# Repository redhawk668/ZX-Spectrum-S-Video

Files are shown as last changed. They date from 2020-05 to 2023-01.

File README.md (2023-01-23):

# Introduction

This PCB replaces the RF modulatorbox on a Sinclair ZX Spectrum computer. It's main purpose is to improve the video output of the ZX Spectrum by seperating the luma/sync (Y) and chroma (C) signals to get rid of the dotcrawl.

# Composite output works, why designing this board?
Why not? I use a RetroTink 2X (https://www.retrotink.com/product-page/retrotink-2x), this little device converts an analog signal to HDMI output. The Spectrum's composite output is absolutely horrible on this. The RetroTink provides an s-video input, that gave me the idea to seperate the Y/C signals to convert the composite output to s-video, improving the video signal. Some googling later I found this thread on the World of Spectrum forums: 

https://www.worldofspectrum.org/forums/discussion/47120/new-video-about-s-video-modification-on-issue-two-48k-spectrum/p1. 

(Credits to MAK1024 and RGA24 for providing the basics for this design).

# The PCB itself

# Rev. A - Simple through hole design (first design)
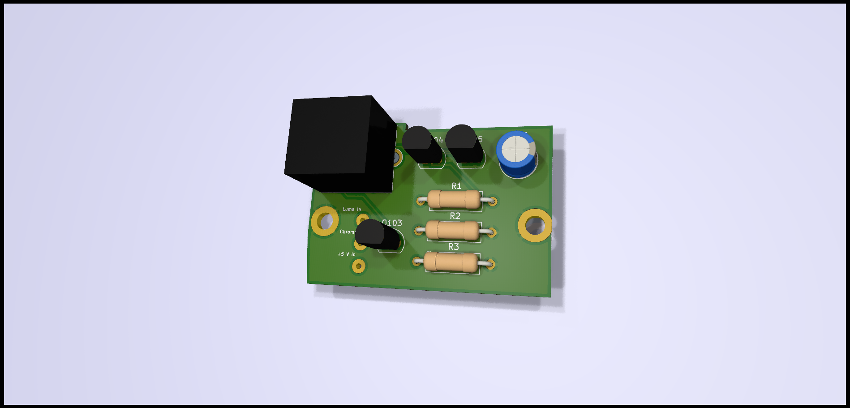
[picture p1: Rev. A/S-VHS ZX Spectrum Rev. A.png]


# Rev. D01 - Final design
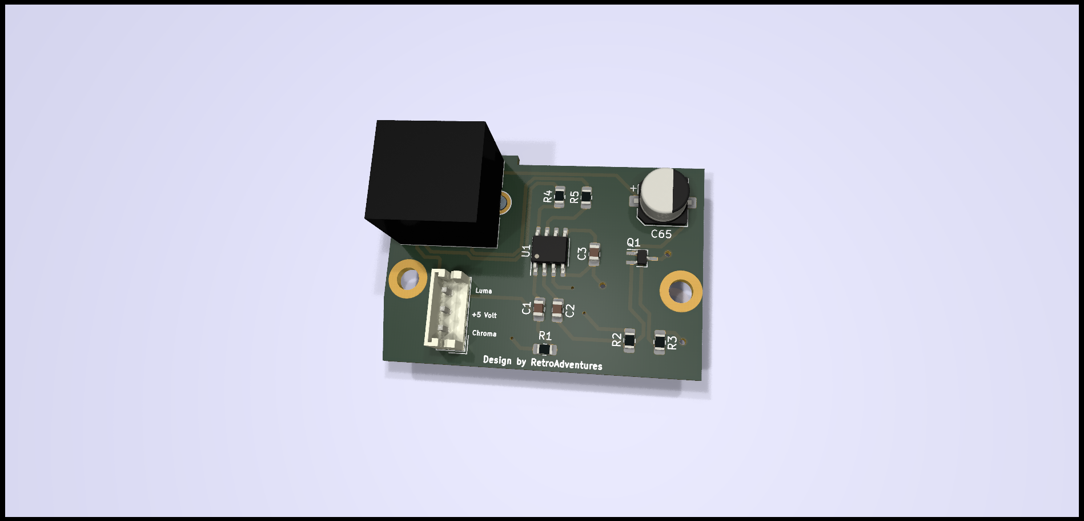
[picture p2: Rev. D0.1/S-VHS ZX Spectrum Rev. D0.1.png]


Rev. A is a through hole design and uses transistors to amplify the signal. 

Rev. D01 is the final design and like the previous Rev. D, based on the THS7314D chip. Two resistors have been removed, this was causing a dim picture on some displays. This design is also a 4-layer with seperated ground/power planes. For the connection to the ZX Spectrum a JST connector is used.

I have included the Gerber files from each design, so you can have the PCB of your choice manufactured by your preferred manufacturer.

# Billing of Materials: Rev. A
- 1x 4 pin mini din chassis (Lumberg TM 0508 A/4)
- 3x NPN Transistors. I've used BC547, but most small signal transistors should be fine.
- 1x 2K2 Resistor
- 1x 3K9 or 1x 4K3 Resistor
- 1x 390R Resistor
- 1x 22uF Electrolytic Capacitor

# Billing of Materials: Rev. D.01 (Final Design)
- J1: 1x 4 pin mini din chassis (Lumberg TM 0508 A/4)
- Q1: BC847, SOT323/SC70
- U1: THS7314D, SOIC-8
- C1: 0,1 uF ceramic capacitor XR7, 0805
- C2: 0,1 uF ceramic capacitor XR7, 0805
- C3: 0,1 uF ceramic capacitor XR7, 0805
- C65: 22 uF aluminium electrolytic capacitor (6,3x5,3)
- R1: 1K thick film resistor, 0805
- R2: 390R thick film resistor, 0805
- R3: 2K2 thick film resistor, 0805
- R4: 75R thick film resistor, 0805
- R5: 75R thick film resistor, 0805
- J2: 3x01 JST connector 2.54mm spacing

# For Rev. A designs (Rev D.01 has JST connector):

- Some wire
- 2x M2.5 screws
- 4x M2.5 nuts

# Summary
Once you have built the little circuit, solder in wires for luma in, chroma in and +5 volt in. Make the wires for luma in and +5 volt about 50mm. PCB layout on an Issue 2 is a bit different than Issue 3 and above. 50mm for the chroma wire should be long enough for an Issue 2. Issue 3 and above needs a bit longer wire. 

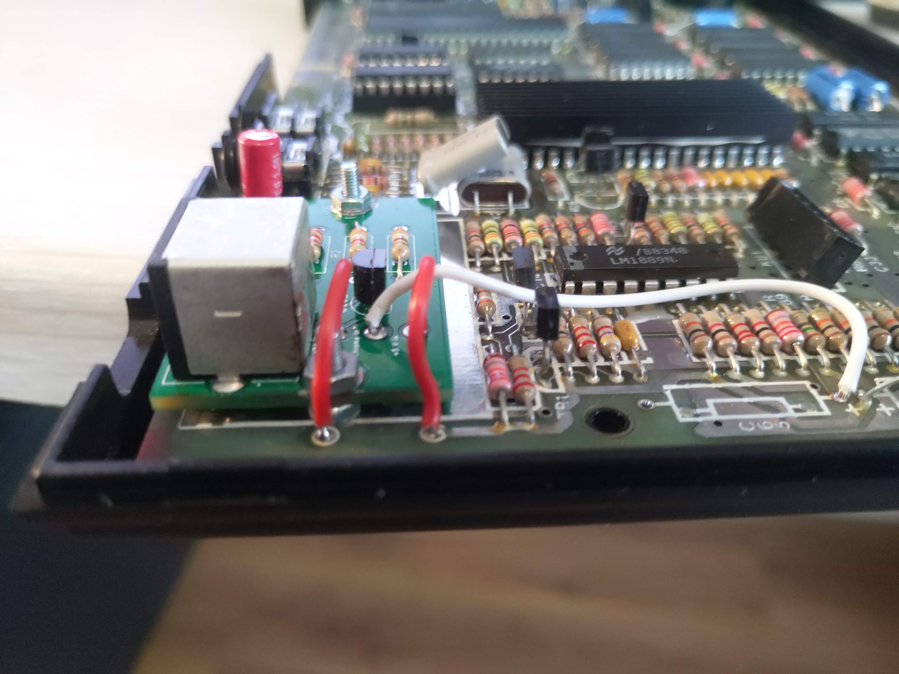
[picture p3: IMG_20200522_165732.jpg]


Now, carefully remove the modulatorbox and capacitor C65 from the Spectrum PCB. Now carefully mount the PCB onto the Spectrum PCB using the screws and nuts (might need drilling, but M2.5 should fit). Seperate the PCB's using one of the nuts on either side. Tighten the PCB to the Spectrum PCB using a nut on either side, as shown in the picture:

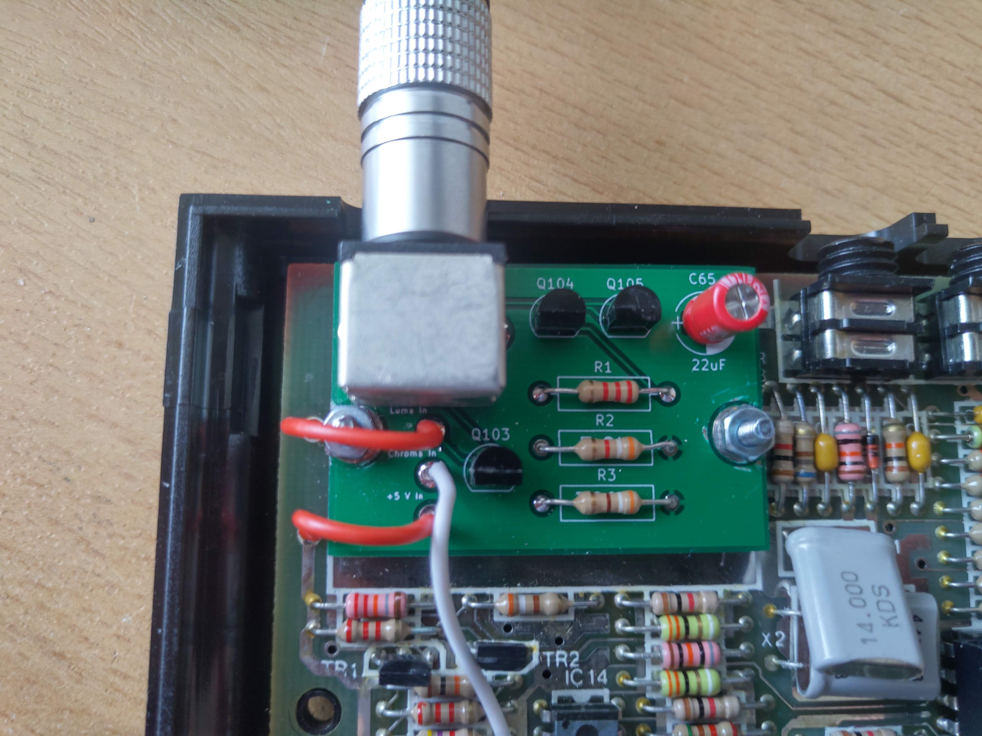
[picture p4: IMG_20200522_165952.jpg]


Now solder the luma and +5 volt into their respective holes. (The composite output on the Spectrum is now the luma output). Solder the chroma wire into the the + side of capacitor C65. On Issue 2 PCB's C65 is underneath the modulator box, on Issue 3 boards and above, C65 is above C25 on the left side of the PCB.

# Issue 2:

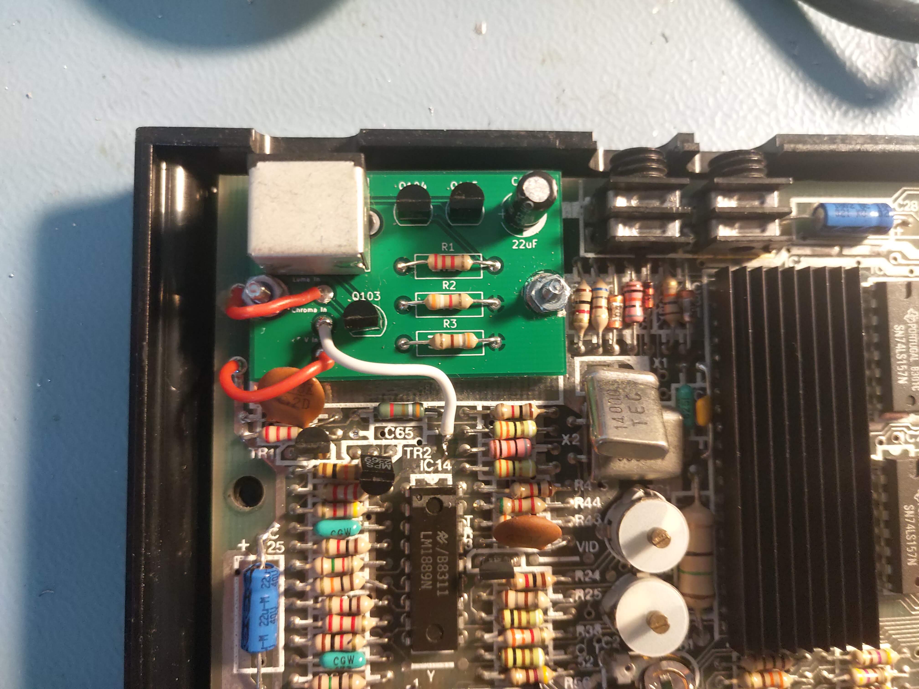
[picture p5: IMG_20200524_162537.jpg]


# Issue 3 and above:



# Rev. D01 connection to ZX Spectrum:

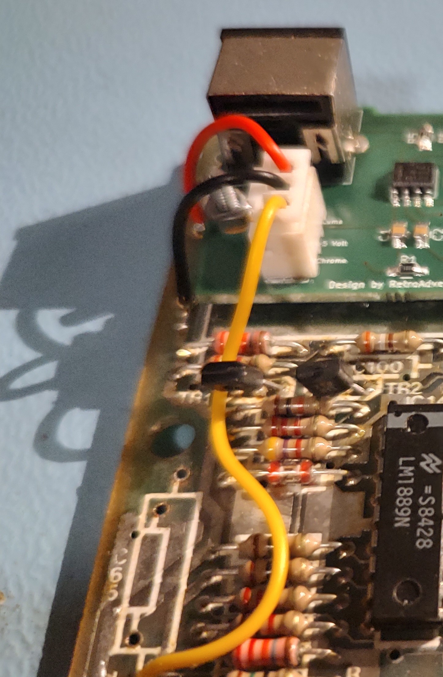
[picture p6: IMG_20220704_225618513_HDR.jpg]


I recommend cutting the pins of the mini din chassis as close to the underside of the PCB as possible, to prevent short circuits. 

# Disclaimer
I am not responsible for any damage to your Spectrum, you do this at your own risk. Take care when you build this and when fitting it to your Spectrum.

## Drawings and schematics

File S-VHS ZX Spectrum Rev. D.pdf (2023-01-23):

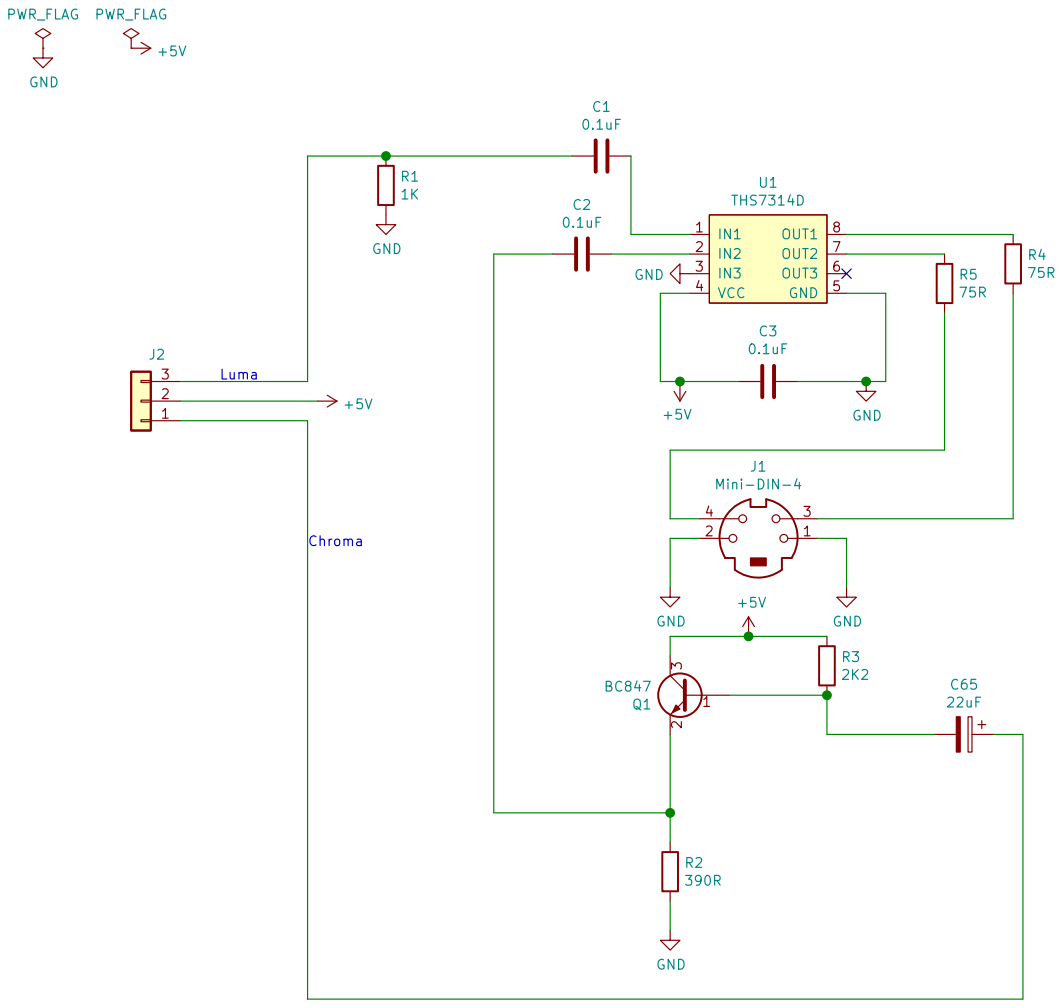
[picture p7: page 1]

File: S-VHS ZX Spectrum Rev. D.sch Sheet: /
Id: 1/1 Title:

ZX Spectrum S-Video Output 19-10-2020

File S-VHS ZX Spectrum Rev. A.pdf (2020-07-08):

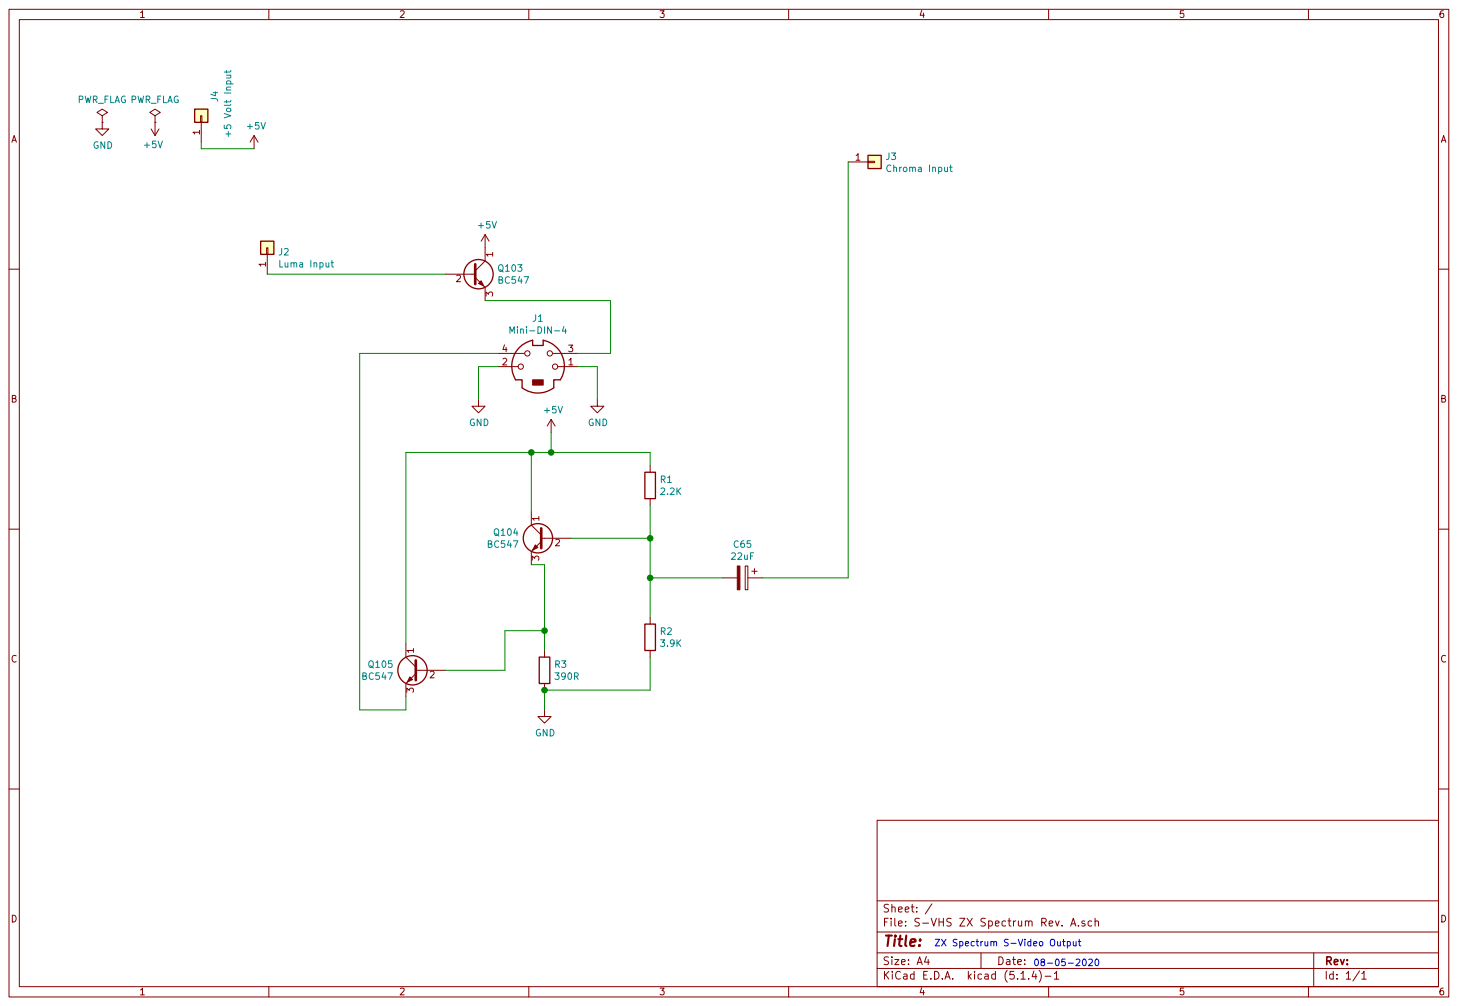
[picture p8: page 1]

File: S-VHS ZX Spectrum Rev. A.sch Sheet: /
Id: 1/1 Title:

ZX Spectrum S-Video Output 08-05-2020

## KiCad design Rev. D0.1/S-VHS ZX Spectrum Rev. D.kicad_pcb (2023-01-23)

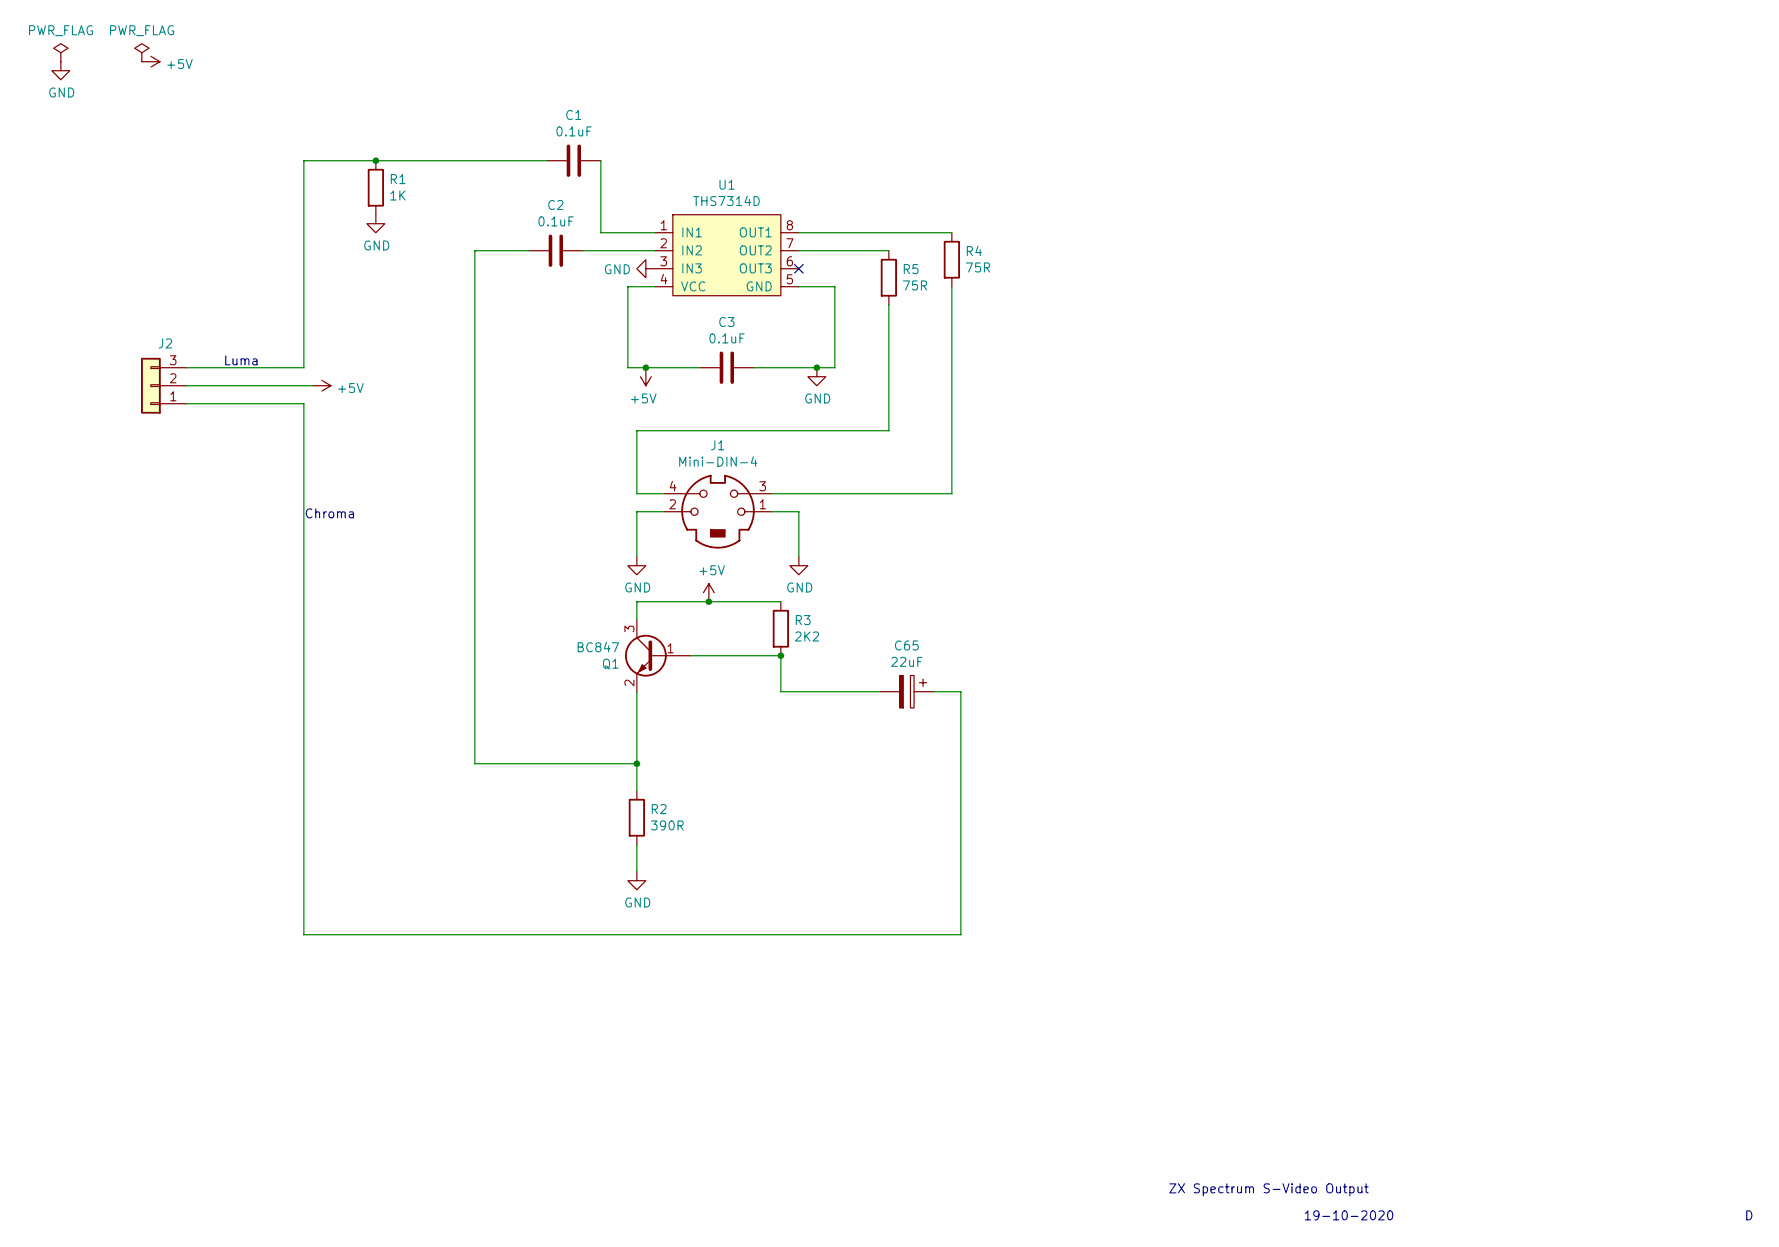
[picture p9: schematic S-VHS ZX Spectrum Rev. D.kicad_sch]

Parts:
C1, C2, C3: 0.1uF; C_0805_2012Metric_Pad1.18x1.45mm_HandSolder
C65: 22uF; CP_Elec_6.3x5.3
J1: Mini-DIN-4; MD40SMK
J2: Conn_01x03; JST_EH_B3B-EH-A_1x03_P2.50mm_Vertical
Q1: BC847; SOT-323_SC-70_Handsoldering
R1: 1K; R_0805_2012Metric_Pad1.20x1.40mm_HandSolder
R2: 390R; R_0805_2012Metric_Pad1.20x1.40mm_HandSolder
R3: 2K2; R_0805_2012Metric_Pad1.20x1.40mm_HandSolder
R4, R5: 75R; R_0805_2012Metric_Pad1.20x1.40mm_HandSolder
U1: THS7314D; SOIC-8_3.9x4.9mm_P1.27mm

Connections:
+5V: C3.1, J2.2, Q1.3 (C), R3.1, U1.4 (VCC)
GND: C3.2, J1.1, J1.2, R1.2, R2.2, U1.3 (IN3), U1.5 (GND); also elsewhere on the board
unnamed: C1.1, U1.1 (IN1)
unnamed: C1.2, J2.3, R1.1
unnamed: C2.1, U1.2 (IN2)
unnamed: C2.2, Q1.2 (E), R2.1
unnamed: C65.1, J2.1
unnamed: C65.2, Q1.1 (B), R3.2
unnamed: J1.3, R4.2
unnamed: J1.4, R5.2
unnamed: R4.1, U1.8 (OUT1)
unnamed: R5.1, U1.7 (OUT2)

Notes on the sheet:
Chroma
Luma
19-10-2020
ZX Spectrum S-Video Output

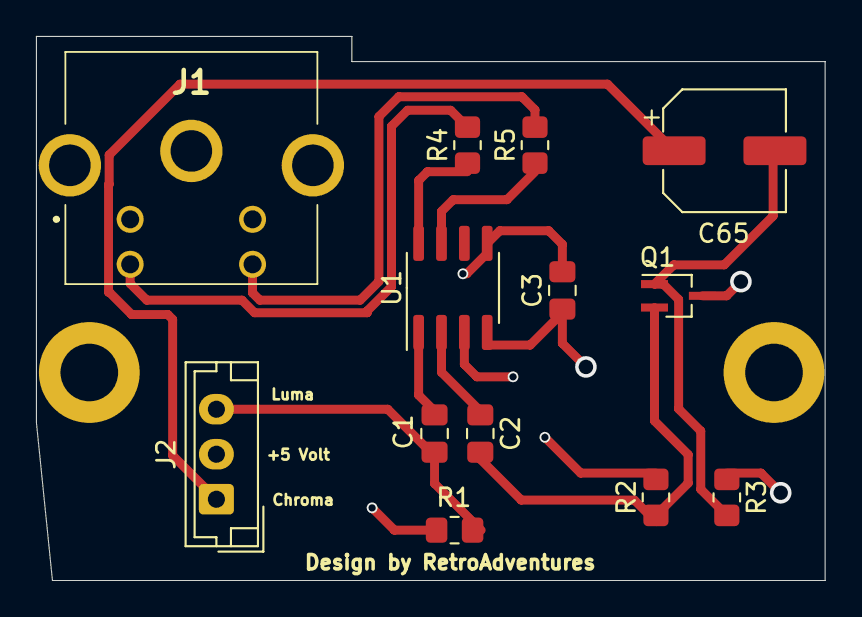
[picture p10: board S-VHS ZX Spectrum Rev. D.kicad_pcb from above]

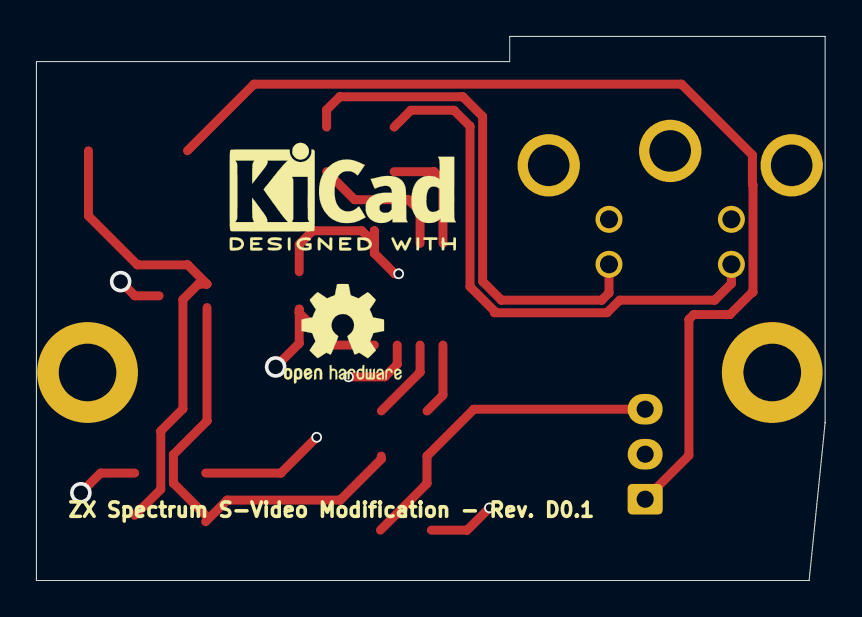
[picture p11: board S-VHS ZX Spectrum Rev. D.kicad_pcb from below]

Board: 4 copper layers, 43.8 x 30.2 mm, 17 parts (2 on the bottom side), 12 nets.

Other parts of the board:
KiCad Logo: KiCad-Logo2_6mm_SilkScreen
Left MountHole: MountingHole_3.2mm_M3_DIN965_Pad
Open Hardware Logo: OSHW-Logo2_7.3x6mm_SilkScreen
Right MountHole: MountingHole_3.2mm_M3_DIN965_Pad

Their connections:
GND: Left MountHole.1, Right MountHole.1; also elsewhere on the board

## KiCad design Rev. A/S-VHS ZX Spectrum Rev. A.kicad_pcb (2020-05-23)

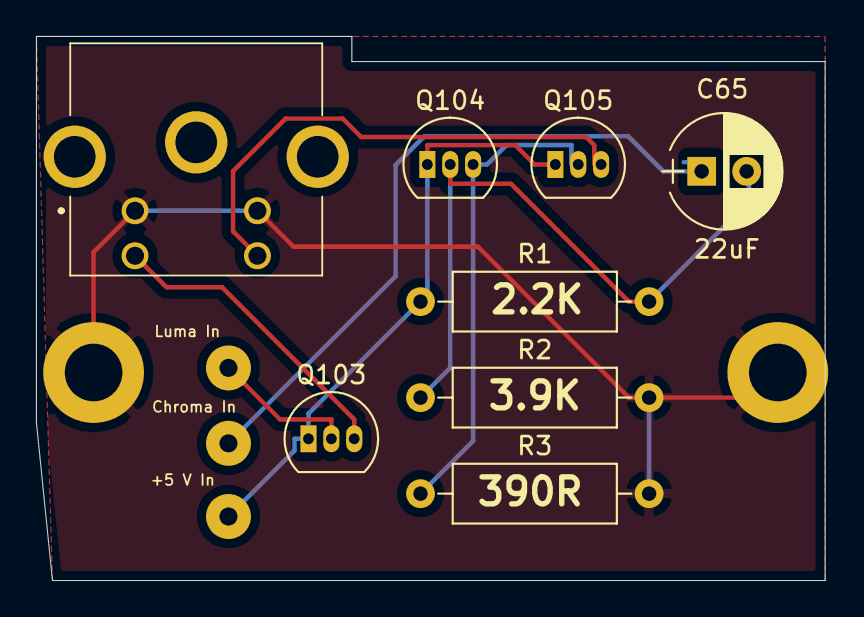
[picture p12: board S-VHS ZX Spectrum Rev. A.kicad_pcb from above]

Board: 2 copper layers, 43.8 x 30.2 mm, 13 parts (0 on the bottom side), 8 nets.

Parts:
C65: 22uF; CP_Radial_D6.3mm_P2.50mm
J1: Mini-DIN-4; MD40SMK
J2, J3, J4: SolderWirePad_single_1mmDrill
Q103, Q104, Q105: BC547; TO-92_Inline_Narrow_Oval
R1: 2.2K; R_Axial_DIN0309_L9.0mm_D3.2mm_P12.70mm_Horizontal
R2: 3.9K; R_Axial_DIN0309_L9.0mm_D3.2mm_P12.70mm_Horizontal
R3: 390R; R_Axial_DIN0309_L9.0mm_D3.2mm_P12.70mm_Horizontal
REF1, REF2: MountingHole_3.2mm_M3_DIN965_Pad

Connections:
+5V: J4.1, Q103.1, Q104.1, Q105.1, R1.1
GND: J1.1, J1.2, R2.2, R3.2, REF1.1, REF2.1
unnamed: C65.1, J3.1
unnamed: C65.2, Q104.2, R1.2, R2.1
unnamed: J1.3, Q103.3
unnamed: J1.4, Q105.3
unnamed: J2.1, Q103.2
unnamed: Q104.3, Q105.2, R3.1

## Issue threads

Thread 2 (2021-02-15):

ZX Spectrum 128K toastrack compatibility

cfrussen, 2021-02-15:
Hello, is this mod compatible with the ZX Spectrum 128K toastrack ?

redhawk668, 2021-02-15:
Unfortunately not, the ZX 128K has a different video circuit based on a TAE2000 video encoder chip.

mvbhz, 2025-07-18:
Will this modification fit the ZX Spectrum+? (ZX Spectrum+ compatibility)?

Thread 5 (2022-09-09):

Get no picture after applying the mod Rev.D

Snocksman, 2022-09-09:
Hi !

I build the mod Rev.D and applied it to my ZX Spectrum - Issue Two Board, but i don´t get any picture anymore...

What could be wrong ? Is there something i can check with the multimeter ? Do I still have to set up the picture with the onboard Potentiometer ?

I measured the voltage on the three connections on the board:

+5V: 4,59V
Chroma in: 3,8V
Luma in: 0V

Is there something wrong with the Luma Signal ?

best regards,
Mathias Klein

Snocksman, 2022-09-09:
OK, found the Problem... On the negative side of the removed capacitor C65 there is a tiny connection, on the backside of the ZX Spectrum board, to the resistor next to C65... When I removed C65 i accidently cut off this connection. The result was, that there was no Luma Signal going to the MOD-Board.

Closed 2022-09-09.

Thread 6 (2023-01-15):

3D printed plate

shred, 2023-01-15:
I found that using only nuts as spacers, gives the board stability issues and might cause shortcuts. So I created a 3D printed plate that goes between the ZX Spectrum and the S-Video board. It gives more stability, and is also insulates the pins of the mini DIN connector from the mainboard.

https://www.printables.com/model/351591-zx-spectrum-s-video-base-plate

License is CC BY-SA. I just want to share it because others might find it useful as well. Feel free to add a link to your README.

Anyway, thank you for this project! The image quality is a lot better than just composite.

flegmatik, 2023-01-26:
Awesome, was just about to design one by myself, thanks!
